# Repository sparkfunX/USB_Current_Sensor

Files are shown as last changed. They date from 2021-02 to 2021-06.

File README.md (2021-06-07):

SparkX USB Current Sensor
========================================

SparkX USB Current Sensor (SPX-18016) (https://www.sparkfun.com/products/18016)

[*SparkX USB Current Sensor (SPX-18016)*](https://www.sparkfun.com/products/18016)

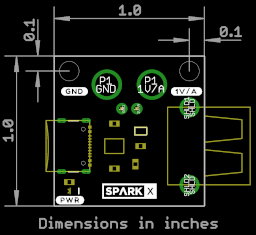
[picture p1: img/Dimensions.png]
SparkX USB Current Sensor


Do you want to be able to measure what current your board is drawing in real time? Maybe it is a board that draws short bursts of current?
Or maybe you want to investigate what in-rush current your board draws? If so, this is the product for you!

The TI INA290 is an ultra-precise current sense amplifier that can measure voltage drops across shunt resistors over a wide common-mode range.
The INA290A1 on our board has a gain of 20 Volts per Volt and we measure the current using a 0.05 Ohm shunt resistor. Together these produce an
output of 1 Volt per Amp. If your board is drawing 100mA, you will see an output of 100mV. The maximum current it can measure is 2 Amps
and we've included a 2A resettable fuse for added protection.

We've provided both 0.1" breakout pads and Gator pads, to make it easy to connect up your multimeter or oscilloscope.
Feed power in via the USB-C socket, and provide power to your board via the USB-A socket.
A pair of [USB 2.0 A to C Cables](https://www.sparkfun.com/products/15092) will allow you to connect the input to your USB port or power supply
and the output to your board.
You might find our [BNC to Alligator Cable](https://www.sparkfun.com/products/504) useful for connecting to your oscilloscope.
Our [Banana to Alligator Coax Cable](https://www.sparkfun.com/products/508) is perfect for connecting your multimeter.

Repository Contents
-------------------
* **/Documents** - datasheets etc.
* **/Hardware** - Eagle design files (.brd, .sch)

Product Versions
----------------
* [SPX-18016](https://www.sparkfun.com/products/18016) - Original SparkX Release.

License Information
-------------------

This product is _**open source**_!

Please review the LICENSE.md file for license information.

If you have any questions or concerns on licensing, please contact technical support on our [SparkFun forums](https://forum.sparkfun.com/viewforum.php?f=152).

Distributed as-is; no warranty is given.

- Your friends at SparkFun.

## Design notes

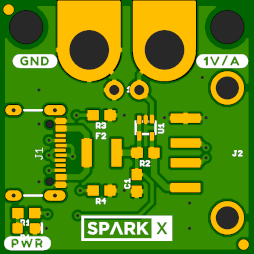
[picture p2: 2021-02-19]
img/Top.png

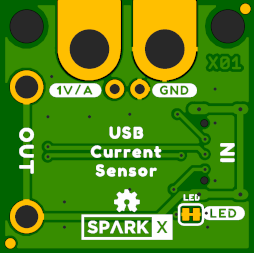
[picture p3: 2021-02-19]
img/Bottom.png

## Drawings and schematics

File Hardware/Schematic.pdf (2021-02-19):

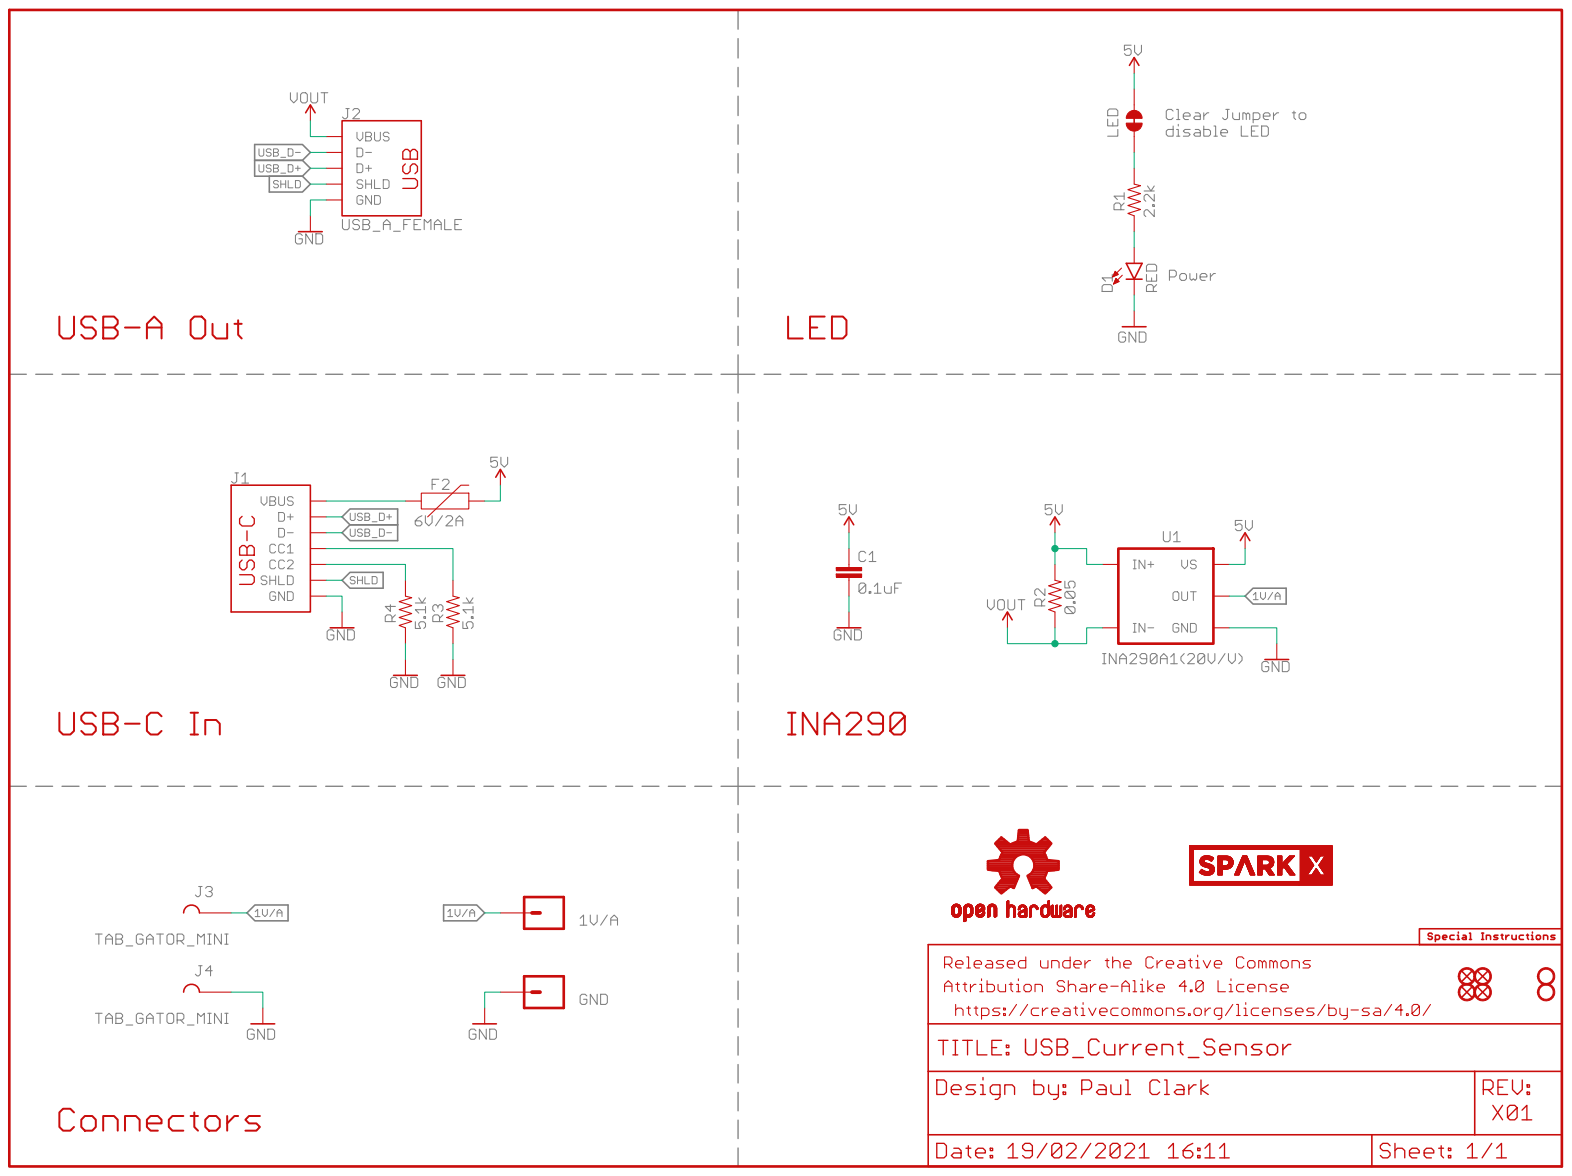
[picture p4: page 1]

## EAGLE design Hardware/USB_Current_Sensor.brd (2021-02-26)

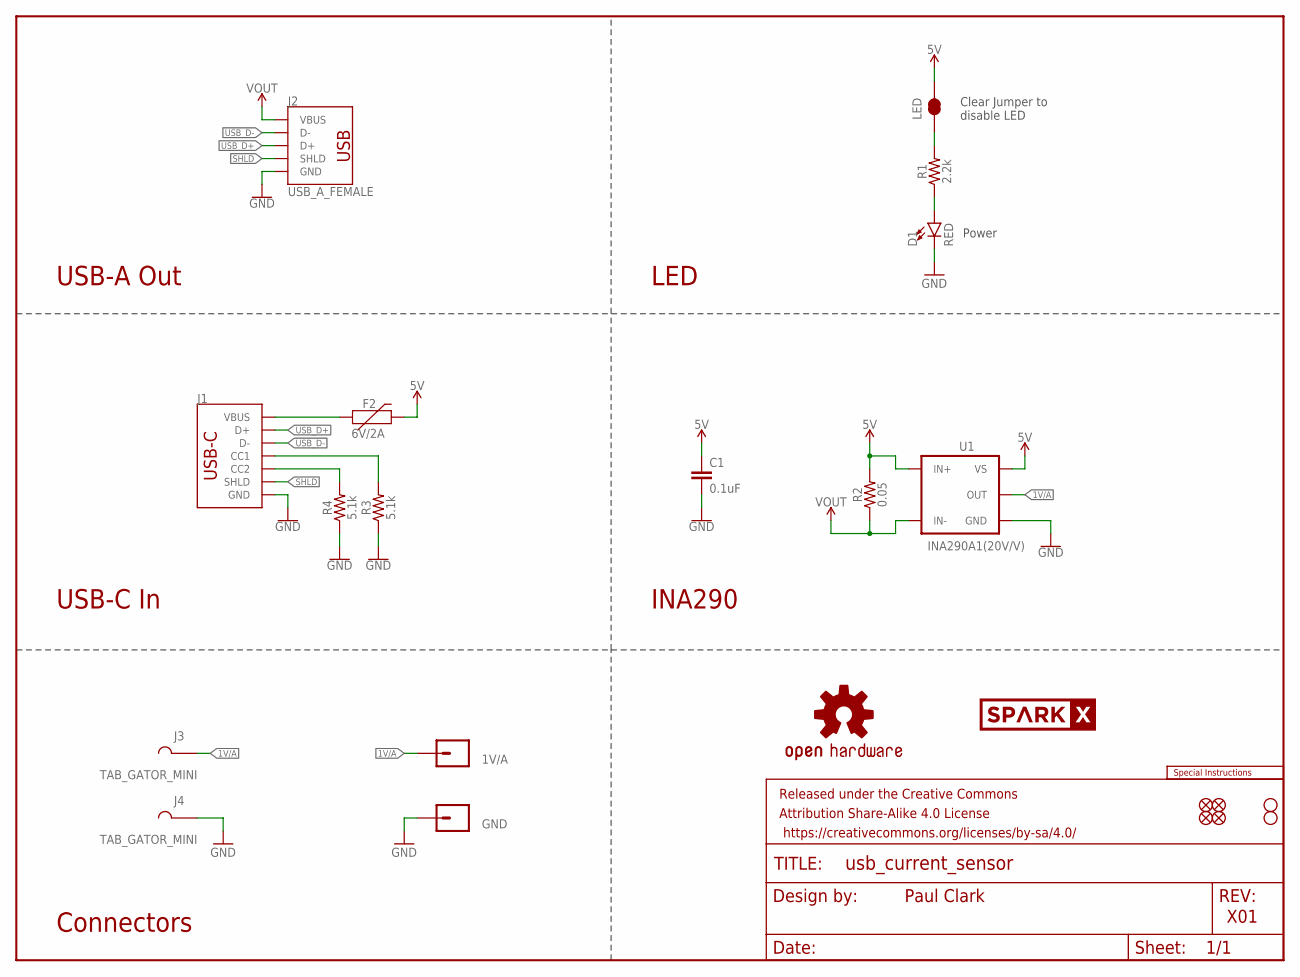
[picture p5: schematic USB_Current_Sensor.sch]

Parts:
1V/A: CONN_01PTH_NO_SILK_YES_STOP; 1X01_NO_SILK
C1: 0.1uF; 0603
D1: RED; LED-0603
F2: 6V/2A; 1210
FRAME1: FRAME-LETTER; CREATIVE_COMMONS
GND: CONN_01PTH_NO_SILK_YES_STOP; 1X01_NO_SILK
J1: USB_C_4-LAYER_PADS; USB-C-16P_4LAYER-PADS
J2: USB_A_FEMALE; USB-A-S-NOSILK-FEMALE
J3, J4: TAB_GATOR_MINI
JP1, JP2, JP5, JP6: FIDUCIAL1X2; FIDUCIAL-1X2
JP3, JP4: STAND-OFF
LED: JUMPER-SMT_2_NC_TRACE_SILK; SMT-JUMPER_2_NC_TRACE_SILK
LOGO1: OSHW-LOGOMINI; OSHW-LOGO-MINI
LOGO2: SPECIAL_INSTRUCTIONS-ORDERING; ORDERING_INSTRUCTIONS
R1: 2.2k; 0603
R2: 0.05; 0603
R3, R4: 5.1k; 0603
U1: INA290A1(20V/V); SC70
U$2: SPARKX-LOGO4; SPARKX-MEDIUM

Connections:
1V/A: 1V/A.1, J3.P1, U1.1 (OUT)
5V: C1.1, F2.2, LED.2, R2.2, U1.3 (VS), U1.4 (IN+)
GND: C1.2, D1.C, GND.1, J1.GND, J1.GND2 (GND), J2.GND, J4.P1, R3.1, R4.1, U1.2 (GND)
unnamed: D1.A, R1.1
unnamed: LED.1, R1.2
unnamed: J1.A5 (CC1), R3.2
unnamed: J1.B5 (CC2), R4.2
unnamed: F2.1, J1.VBUS1 (VBUS), J1.VBUS2 (VBUS)
SHLD: J1.SHLD1 (SHLD), J1.SHLD2 (SHLD), J1.SHLD3 (SHLD), J1.SHLD4 (SHLD), J2.SHLD1 (SHLD), J2.SHLD2 (SHLD)
USB_D+: J1.A6 (D+), J1.B6 (D+), J2.D+
USB_D-: J1.A7 (D-), J1.B7 (D-), J2.D-
VOUT: J2.VBUS, R2.1, U1.5 (IN-)

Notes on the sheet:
Paul Clark
X01
Power
Connectors
Clear Jumper to disable LED
LED
INA290
USB-C In
USB-A Out

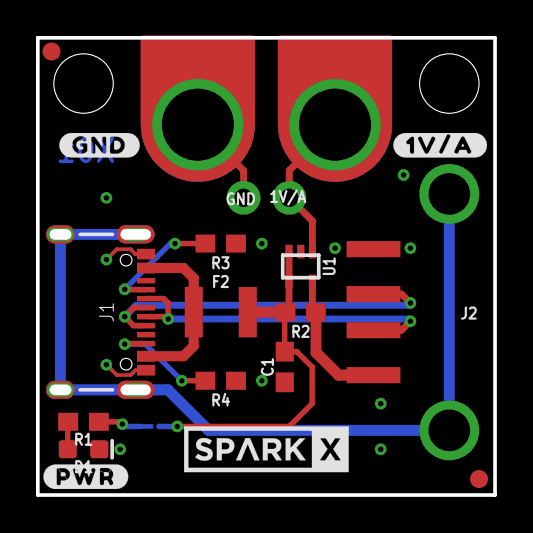
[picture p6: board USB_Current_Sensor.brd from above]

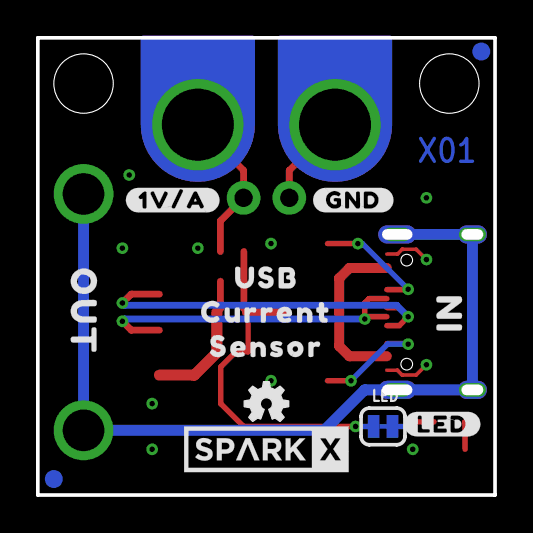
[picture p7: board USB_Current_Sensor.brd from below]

Board: 2 copper layers, 25.4 x 25.4 mm, 37 parts (13 on the bottom side), 12 nets.

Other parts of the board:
U$1: SPARKX-LOGO4; SPARKX-MEDIUM
U$3, U$4: #GND#0
U$5, U$6: #1V#A#0
U$7: USB0
U$8: CURRENT0
U$9: SENSOR0
U$10: IN0
U$11: OUT0
U$13: #PWR#0
U$14: #LED#0

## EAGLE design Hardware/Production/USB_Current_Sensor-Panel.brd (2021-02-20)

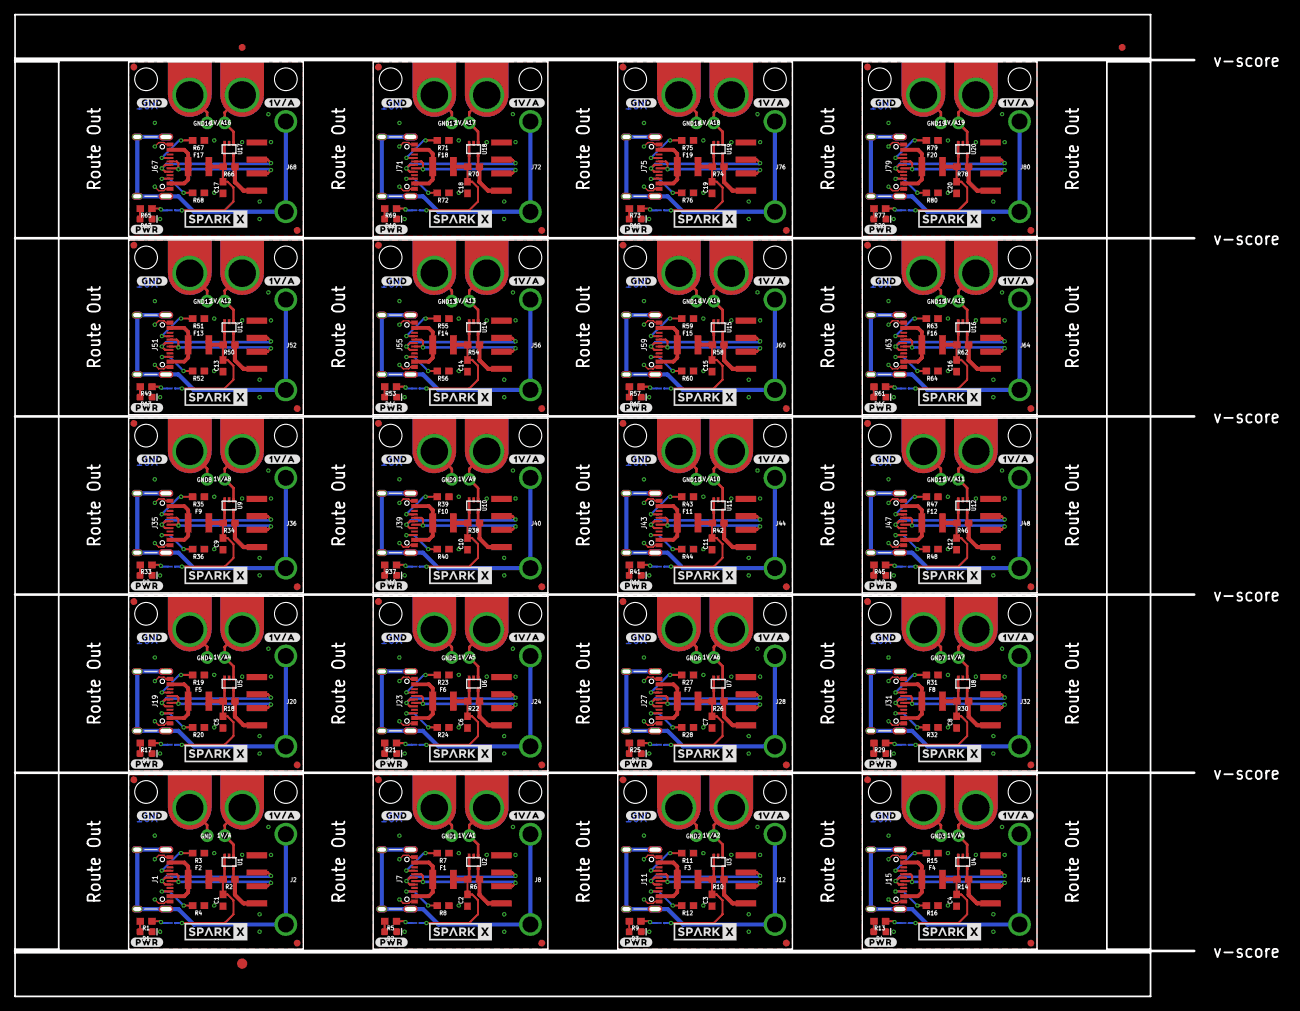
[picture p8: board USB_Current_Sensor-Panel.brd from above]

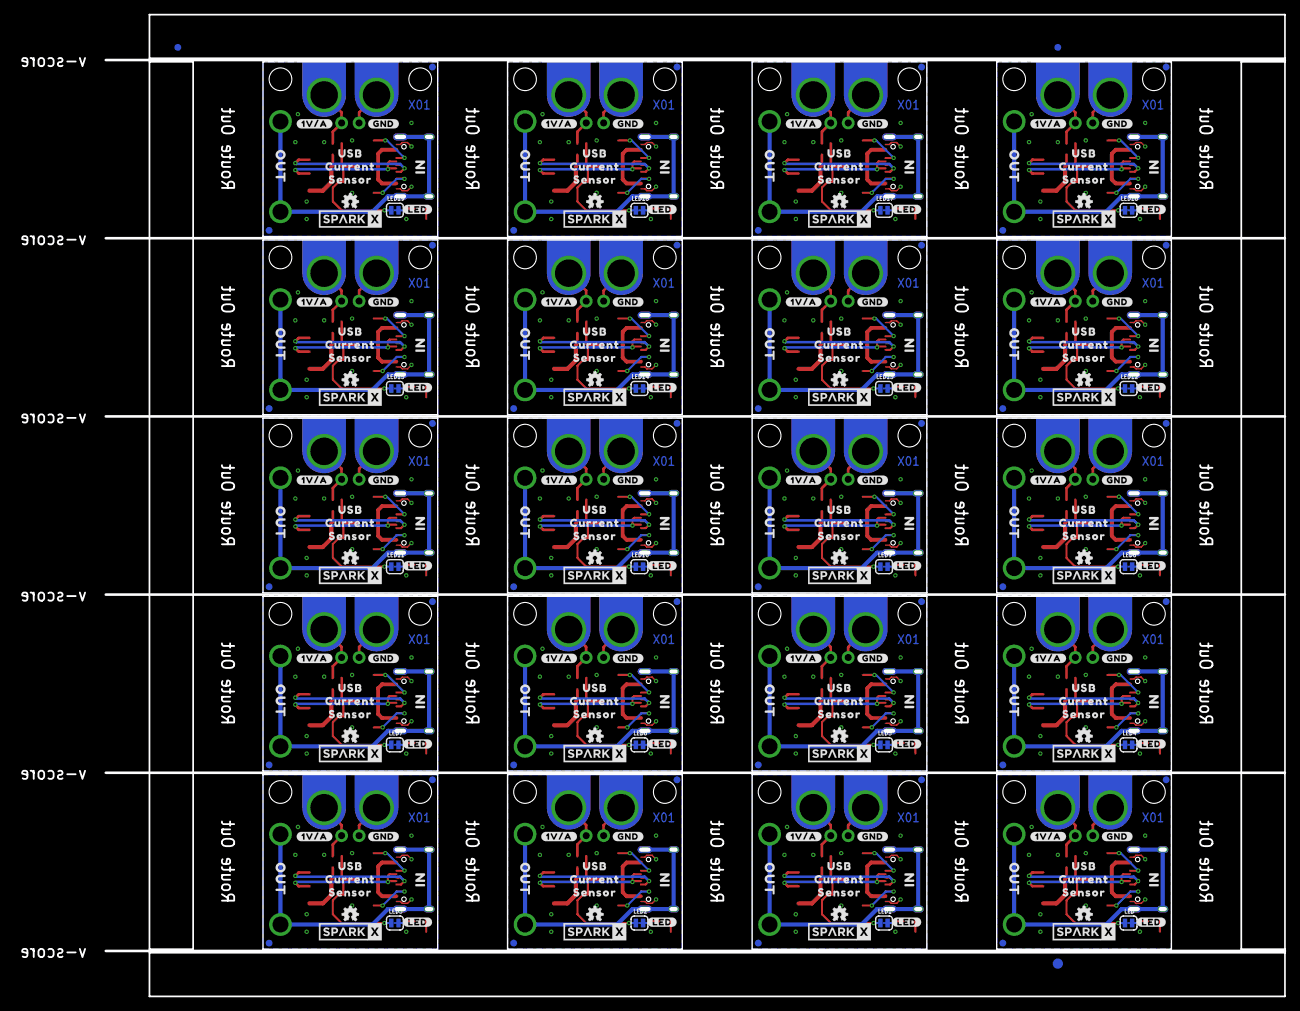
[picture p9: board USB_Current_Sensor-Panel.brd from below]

Board: 2 copper layers, 171.4 x 142.7 mm, 706 parts (263 on the bottom side), 240 nets.

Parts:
1V/A, 1V/A1, 1V/A2, 1V/A3, 1V/A4, 1V/A5, 1V/A6, 1V/A7, 1V/A8, 1V/A9, 1V/A10, 1V/A11, 1V/A12, 1V/A13, 1V/A14, 1V/A15, 1V/A16, 1V/A17, 1V/A18, 1V/A19: 1X01_NO_SILK
C1, C2, C3, C4, C5, C6, C7, C8, C9, C10, C11, C12, C13, C14, C15, C16, C17, C18, C19, C20: 0.1uF; 0603
D1, D2, D3, D4, D5, D6, D7, D8, D9, D10, D11, D12, D13, D14, D15, D16, D17, D18, D19, D20: RED; LED-0603
E$1, E$2, E$3, E$4: FIDUCIAL-1X2
E$5, E$6: FIDUCIAL-1.5X3
F1, F2, F3, F4, F5, F6, F7, F8, F9, F10, F11, F12, F13, F14, F15, F16, F17, F18, F19, F20: 6V/2A; 1210
GND, GND1, GND2, GND3, GND4, GND5, GND6, GND7, GND8, GND9, GND10, GND11, GND12, GND13, GND14, GND15, GND16, GND17, GND18, GND19: 1X01_NO_SILK
J1, J7, J11, J15, J19, J23, J27, J31, J35, J39, J43, J47, J51, J55, J59, J63, J67, J71, J75, J79: USB-C-16P_4LAYER-PADS
J2, J8, J12, J16, J20, J24, J28, J32, J36, J40, J44, J48, J52, J56, J60, J64, J68, J72, J76, J80: USB_A_FEMALE; USB-A-S-NOSILK-FEMALE
J3, J4, J5, J6, J9, J10, J13, J14, J17, J18, J21, J22, J25, J26, J29, J30, J33, J34, J37, J38, J41, J42, J45, J46, J49, J50, J53, J54, J57, J58, J61, J62, J65, J66, J69, J70, J73, J74, J77, J78: TAB_GATOR_MINI
JP1, JP2, JP5, JP6, JP9, JP10, JP11, JP12, JP15, JP16, JP17, JP18, JP21, JP22, JP23, JP24, JP27, JP28, JP29, JP30, JP33, JP34, JP35, JP36, JP39, JP40, JP41, JP42, JP45, JP46, JP47, JP48, JP51, JP52, JP53, JP54, JP57, JP58, JP59, JP60, JP63, JP64, JP65, JP66, JP69, JP70, JP71, JP72, JP75, JP76, JP77, JP78, JP81, JP82, JP83, JP84, JP87, JP88, JP89, JP90, JP93, JP94, JP95, JP96, JP99, JP100, JP101, JP102, JP105, JP106, JP107, JP108, JP111, JP112, JP113, JP114, JP117, JP118, JP119, JP120: FIDUCIAL1X2; FIDUCIAL-1X2
JP3, JP4, JP7, JP8, JP13, JP14, JP19, JP20, JP25, JP26, JP31, JP32, JP37, JP38, JP43, JP44, JP49, JP50, JP55, JP56, JP61, JP62, JP67, JP68, JP73, JP74, JP79, JP80, JP85, JP86, JP91, JP92, JP97, JP98, JP103, JP104, JP109, JP110, JP115, JP116: STAND-OFF
LED, LED1, LED2, LED3, LED4, LED5, LED6, LED7, LED8, LED9, LED10, LED11, LED12, LED13, LED14, LED15, LED16, LED17, LED18, LED19: SMT-JUMPER_2_NC_TRACE_SILK
LOGO1, LOGO2, LOGO3, LOGO4, LOGO5, LOGO6, LOGO7, LOGO8, LOGO9, LOGO10, LOGO11, LOGO12, LOGO13, LOGO14, LOGO15, LOGO16, LOGO17, LOGO18, LOGO19, LOGO20: OSHW-LOGOMINI; OSHW-LOGO-MINI
R1, R5, R9, R13, R17, R21, R25, R29, R33, R37, R41, R45, R49, R53, R57, R61, R65, R69, R73, R77: 2.2k; 0603
R2, R6, R10, R14, R18, R22, R26, R30, R34, R38, R42, R46, R50, R54, R58, R62, R66, R70, R74, R78: 0.05; 0603
R3, R4, R7, R8, R11, R12, R15, R16, R19, R20, R23, R24, R27, R28, R31, R32, R35, R36, R39, R40, R43, R44, R47, R48, R51, R52, R55, R56, R59, R60, R63, R64, R67, R68, R71, R72, R75, R76, R79, R80: 5.1k; 0603
U1, U2, U3, U4, U5, U6, U7, U8, U9, U10, U11, U12, U13, U14, U15, U16, U17, U18, U19, U20: INA290A1(20V/V); SC70
U$1, U$2, U$12, U$17, U$27, U$30, U$40, U$43, U$53, U$56, U$66, U$69, U$79, U$82, U$92, U$95, U$105, U$108, U$118, U$121, U$131, U$134, U$144, U$147, U$157, U$160, U$170, U$173, U$183, U$186, U$196, U$199, U$209, U$212, U$222, U$225, U$235, U$238, U$248, U$251: SPARKX-LOGO4; SPARKX-MEDIUM
U$3, U$4, U$18, U$19, U$31, U$32, U$44, U$45, U$57, U$58, U$70, U$71, U$83, U$84, U$96, U$97, U$109, U$110, U$122, U$123, U$135, U$136, U$148, U$149, U$161, U$162, U$174, U$175, U$187, U$188, U$200, U$201, U$213, U$214, U$226, U$227, U$239, U$240, U$252, U$253: #GND#0
U$5, U$6, U$20, U$21, U$33, U$34, U$46, U$47, U$59, U$60, U$72, U$73, U$85, U$86, U$98, U$99, U$111, U$112, U$124, U$125, U$137, U$138, U$150, U$151, U$163, U$164, U$176, U$177, U$189, U$190, U$202, U$203, U$215, U$216, U$228, U$229, U$241, U$242, U$254, U$255: #1V#A#0
U$7, U$22, U$35, U$48, U$61, U$74, U$87, U$100, U$113, U$126, U$139, U$152, U$165, U$178, U$191, U$204, U$217, U$230, U$243, U$256: USB0
U$8, U$23, U$36, U$49, U$62, U$75, U$88, U$101, U$114, U$127, U$140, U$153, U$166, U$179, U$192, U$205, U$218, U$231, U$244, U$257: CURRENT0
U$9, U$24, U$37, U$50, U$63, U$76, U$89, U$102, U$115, U$128, U$141, U$154, U$167, U$180, U$193, U$206, U$219, U$232, U$245, U$258: SENSOR0
U$10, U$25, U$38, U$51, U$64, U$77, U$90, U$103, U$116, U$129, U$142, U$155, U$168, U$181, U$194, U$207, U$220, U$233, U$246, U$259: IN0
U$11, U$26, U$39, U$52, U$65, U$78, U$91, U$104, U$117, U$130, U$143, U$156, U$169, U$182, U$195, U$208, U$221, U$234, U$247, U$260: OUT0
U$13, U$15, U$28, U$41, U$54, U$67, U$80, U$93, U$106, U$119, U$132, U$145, U$158, U$171, U$184, U$197, U$210, U$223, U$236, U$249: #PWR#0
U$14, U$16, U$29, U$42, U$55, U$68, U$81, U$94, U$107, U$120, U$133, U$146, U$159, U$172, U$185, U$198, U$211, U$224, U$237, U$250: #LED#0

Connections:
1V/A: 1V/A.1, J3.P1, U1.1
1V/A1: 1V/A1.1, J5.P1, U2.1
1V/A2: 1V/A2.1, J9.P1, U3.1
1V/A3: 1V/A3.1, J13.P1, U4.1
1V/A4: 1V/A4.1, J17.P1, U5.1
1V/A5: 1V/A5.1, J21.P1, U6.1
1V/A6: 1V/A6.1, J25.P1, U7.1
1V/A7: 1V/A7.1, J29.P1, U8.1
1V/A8: 1V/A8.1, J33.P1, U9.1
1V/A9: 1V/A9.1, J37.P1, U10.1
1V/A10: 1V/A10.1, J41.P1, U11.1
1V/A11: 1V/A11.1, J45.P1, U12.1
1V/A12: 1V/A12.1, J49.P1, U13.1
1V/A13: 1V/A13.1, J53.P1, U14.1
1V/A14: 1V/A14.1, J57.P1, U15.1
1V/A15: 1V/A15.1, J61.P1, U16.1
1V/A16: 1V/A16.1, J65.P1, U17.1
1V/A17: 1V/A17.1, J69.P1, U18.1
1V/A18: 1V/A18.1, J73.P1, U19.1
1V/A19: 1V/A19.1, J77.P1, U20.1
5V: C1.1, F2.2, LED.2, R2.2, U1.3, U1.4
5V1: C2.1, F1.2, LED1.2, R6.2, U2.3, U2.4
5V2: C3.1, F3.2, LED2.2, R10.2, U3.3, U3.4
5V3: C4.1, F4.2, LED3.2, R14.2, U4.3, U4.4
5V4: C5.1, F5.2, LED4.2, R18.2, U5.3, U5.4
5V5: C6.1, F6.2, LED5.2, R22.2, U6.3, U6.4
5V6: C7.1, F7.2, LED6.2, R26.2, U7.3, U7.4
5V7: C8.1, F8.2, LED7.2, R30.2, U8.3, U8.4
5V8: C9.1, F9.2, LED8.2, R34.2, U9.3, U9.4
5V9: C10.1, F10.2, LED9.2, R38.2, U10.3, U10.4
5V10: C11.1, F11.2, LED10.2, R42.2, U11.3, U11.4
5V11: C12.1, F12.2, LED11.2, R46.2, U12.3, U12.4
5V12: C13.1, F13.2, LED12.2, R50.2, U13.3, U13.4
5V13: C14.1, F14.2, LED13.2, R54.2, U14.3, U14.4
5V14: C15.1, F15.2, LED14.2, R58.2, U15.3, U15.4
5V15: C16.1, F16.2, LED15.2, R62.2, U16.3, U16.4
5V16: C17.1, F17.2, LED16.2, R66.2, U17.3, U17.4
5V17: C18.1, F18.2, LED17.2, R70.2, U18.3, U18.4
5V18: C19.1, F19.2, LED18.2, R74.2, U19.3, U19.4
5V19: C20.1, F20.2, LED19.2, R78.2, U20.3, U20.4
GND: C1.2, D1.C, GND.1, J1.GND, J1.GND2, J2.GND, J4.P1, R3.1, R4.1, U1.2
GND1: C2.2, D2.C, GND1.1, J6.P1, J7.GND, J7.GND2, J8.GND, R7.1, R8.1, U2.2
GND2: C3.2, D3.C, GND2.1, J10.P1, J11.GND, J11.GND2, J12.GND, R11.1, R12.1, U3.2
GND3: C4.2, D4.C, GND3.1, J14.P1, J15.GND, J15.GND2, J16.GND, R15.1, R16.1, U4.2
GND4: C5.2, D5.C, GND4.1, J18.P1, J19.GND, J19.GND2, J20.GND, R19.1, R20.1, U5.2
GND5: C6.2, D6.C, GND5.1, J22.P1, J23.GND, J23.GND2, J24.GND, R23.1, R24.1, U6.2
GND6: C7.2, D7.C, GND6.1, J26.P1, J27.GND, J27.GND2, J28.GND, R27.1, R28.1, U7.2
GND7: C8.2, D8.C, GND7.1, J30.P1, J31.GND, J31.GND2, J32.GND, R31.1, R32.1, U8.2
GND8: C9.2, D9.C, GND8.1, J34.P1, J35.GND, J35.GND2, J36.GND, R35.1, R36.1, U9.2
GND9: C10.2, D10.C, GND9.1, J38.P1, J39.GND, J39.GND2, J40.GND, R39.1, R40.1, U10.2
GND10: C11.2, D11.C, GND10.1, J42.P1, J43.GND, J43.GND2, J44.GND, R43.1, R44.1, U11.2
GND11: C12.2, D12.C, GND11.1, J46.P1, J47.GND, J47.GND2, J48.GND, R47.1, R48.1, U12.2
GND12: C13.2, D13.C, GND12.1, J50.P1, J51.GND, J51.GND2, J52.GND, R51.1, R52.1, U13.2
GND13: C14.2, D14.C, GND13.1, J54.P1, J55.GND, J55.GND2, J56.GND, R55.1, R56.1, U14.2
GND14: C15.2, D15.C, GND14.1, J58.P1, J59.GND, J59.GND2, J60.GND, R59.1, R60.1, U15.2
GND15: C16.2, D16.C, GND15.1, J62.P1, J63.GND, J63.GND2, J64.GND, R63.1, R64.1, U16.2
GND16: C17.2, D17.C, GND16.1, J66.P1, J67.GND, J67.GND2, J68.GND, R67.1, R68.1, U17.2
GND17: C18.2, D18.C, GND17.1, J70.P1, J71.GND, J71.GND2, J72.GND, R71.1, R72.1, U18.2
GND18: C19.2, D19.C, GND18.1, J74.P1, J75.GND, J75.GND2, J76.GND, R75.1, R76.1, U19.2
GND19: C20.2, D20.C, GND19.1, J78.P1, J79.GND, J79.GND2, J80.GND, R79.1, R80.1, U20.2
unnamed: D2.A, R5.1
unnamed: LED1.1, R5.2
unnamed: D1.A, R1.1
unnamed: LED.1, R1.2
unnamed: J7.A5, R7.2
unnamed: J7.B5, R8.2
unnamed: F1.1, J7.VBUS1, J7.VBUS2
unnamed: D3.A, R9.1
unnamed: LED2.1, R9.2
unnamed: J1.A5, R3.2
unnamed: J1.B5, R4.2
unnamed: J11.A5, R11.2
unnamed: J11.B5, R12.2
unnamed: F3.1, J11.VBUS1, J11.VBUS2
unnamed: D4.A, R13.1
unnamed: LED3.1, R13.2
unnamed: J15.A5, R15.2
unnamed: J15.B5, R16.2
unnamed: F2.1, J1.VBUS1, J1.VBUS2
unnamed: F4.1, J15.VBUS1, J15.VBUS2
unnamed: D5.A, R17.1
unnamed: LED4.1, R17.2
unnamed: J19.A5, R19.2
unnamed: J19.B5, R20.2
unnamed: F5.1, J19.VBUS1, J19.VBUS2
unnamed: D6.A, R21.1
unnamed: LED5.1, R21.2
unnamed: J23.A5, R23.2
unnamed: J23.B5, R24.2
unnamed: F6.1, J23.VBUS1, J23.VBUS2
unnamed: D7.A, R25.1
unnamed: LED6.1, R25.2
unnamed: J27.A5, R27.2
unnamed: J27.B5, R28.2
unnamed: F7.1, J27.VBUS1, J27.VBUS2
unnamed: D8.A, R29.1
unnamed: LED7.1, R29.2
unnamed: J31.A5, R31.2
unnamed: J31.B5, R32.2
unnamed: F8.1, J31.VBUS1, J31.VBUS2
unnamed: D9.A, R33.1
unnamed: LED8.1, R33.2
unnamed: J35.A5, R35.2
unnamed: J35.B5, R36.2
unnamed: F9.1, J35.VBUS1, J35.VBUS2
unnamed: D10.A, R37.1
unnamed: LED9.1, R37.2
unnamed: J39.A5, R39.2
unnamed: J39.B5, R40.2
unnamed: F10.1, J39.VBUS1, J39.VBUS2
unnamed: D11.A, R41.1
unnamed: LED10.1, R41.2
unnamed: J43.A5, R43.2
unnamed: J43.B5, R44.2
unnamed: F11.1, J43.VBUS1, J43.VBUS2
unnamed: D12.A, R45.1
unnamed: LED11.1, R45.2
unnamed: J47.A5, R47.2
unnamed: J47.B5, R48.2
unnamed: F12.1, J47.VBUS1, J47.VBUS2
unnamed: D13.A, R49.1
unnamed: LED12.1, R49.2
unnamed: J51.A5, R51.2
unnamed: J51.B5, R52.2
unnamed: F13.1, J51.VBUS1, J51.VBUS2
unnamed: D14.A, R53.1
unnamed: LED13.1, R53.2
unnamed: J55.A5, R55.2
unnamed: J55.B5, R56.2
unnamed: F14.1, J55.VBUS1, J55.VBUS2
unnamed: D15.A, R57.1
unnamed: LED14.1, R57.2
unnamed: J59.A5, R59.2
unnamed: J59.B5, R60.2
unnamed: F15.1, J59.VBUS1, J59.VBUS2
unnamed: D16.A, R61.1
unnamed: LED15.1, R61.2
unnamed: J63.A5, R63.2
unnamed: J63.B5, R64.2
unnamed: F16.1, J63.VBUS1, J63.VBUS2
unnamed: D17.A, R65.1
unnamed: LED16.1, R65.2
unnamed: J67.A5, R67.2
unnamed: J67.B5, R68.2
unnamed: F17.1, J67.VBUS1, J67.VBUS2
unnamed: D18.A, R69.1
unnamed: LED17.1, R69.2
unnamed: J71.A5, R71.2
unnamed: J71.B5, R72.2
unnamed: F18.1, J71.VBUS1, J71.VBUS2
unnamed: D19.A, R73.1
unnamed: LED18.1, R73.2
unnamed: J75.A5, R75.2
unnamed: J75.B5, R76.2
unnamed: F19.1, J75.VBUS1, J75.VBUS2
unnamed: D20.A, R77.1
unnamed: LED19.1, R77.2
unnamed: J79.A5, R79.2
unnamed: J79.B5, R80.2
unnamed: F20.1, J79.VBUS1, J79.VBUS2
SHLD: J1.SHLD1, J1.SHLD2, J1.SHLD3, J1.SHLD4, J2.SHLD1, J2.SHLD2
SHLD1: J7.SHLD1, J7.SHLD2, J7.SHLD3, J7.SHLD4, J8.SHLD1, J8.SHLD2
SHLD2: J11.SHLD1, J11.SHLD2, J11.SHLD3, J11.SHLD4, J12.SHLD1, J12.SHLD2
SHLD3: J15.SHLD1, J15.SHLD2, J15.SHLD3, J15.SHLD4, J16.SHLD1, J16.SHLD2
SHLD4: J19.SHLD1, J19.SHLD2, J19.SHLD3, J19.SHLD4, J20.SHLD1, J20.SHLD2
SHLD5: J23.SHLD1, J23.SHLD2, J23.SHLD3, J23.SHLD4, J24.SHLD1, J24.SHLD2
SHLD6: J27.SHLD1, J27.SHLD2, J27.SHLD3, J27.SHLD4, J28.SHLD1, J28.SHLD2
SHLD7: J31.SHLD1, J31.SHLD2, J31.SHLD3, J31.SHLD4, J32.SHLD1, J32.SHLD2
SHLD8: J35.SHLD1, J35.SHLD2, J35.SHLD3, J35.SHLD4, J36.SHLD1, J36.SHLD2
SHLD9: J39.SHLD1, J39.SHLD2, J39.SHLD3, J39.SHLD4, J40.SHLD1, J40.SHLD2
SHLD10: J43.SHLD1, J43.SHLD2, J43.SHLD3, J43.SHLD4, J44.SHLD1, J44.SHLD2
SHLD11: J47.SHLD1, J47.SHLD2, J47.SHLD3, J47.SHLD4, J48.SHLD1, J48.SHLD2
SHLD12: J51.SHLD1, J51.SHLD2, J51.SHLD3, J51.SHLD4, J52.SHLD1, J52.SHLD2
SHLD13: J55.SHLD1, J55.SHLD2, J55.SHLD3, J55.SHLD4, J56.SHLD1, J56.SHLD2
SHLD14: J59.SHLD1, J59.SHLD2, J59.SHLD3, J59.SHLD4, J60.SHLD1, J60.SHLD2
SHLD15: J63.SHLD1, J63.SHLD2, J63.SHLD3, J63.SHLD4, J64.SHLD1, J64.SHLD2
SHLD16: J67.SHLD1, J67.SHLD2, J67.SHLD3, J67.SHLD4, J68.SHLD1, J68.SHLD2
SHLD17: J71.SHLD1, J71.SHLD2, J71.SHLD3, J71.SHLD4, J72.SHLD1, J72.SHLD2
SHLD18: J75.SHLD1, J75.SHLD2, J75.SHLD3, J75.SHLD4, J76.SHLD1, J76.SHLD2
SHLD19: J79.SHLD1, J79.SHLD2, J79.SHLD3, J79.SHLD4, J80.SHLD1, J80.SHLD2
USB_D+: J1.A6, J1.B6, J2.D+
USB_D+1: J7.A6, J7.B6, J8.D+
USB_D+2: J11.A6, J11.B6, J12.D+
USB_D+3: J15.A6, J15.B6, J16.D+
USB_D+4: J19.A6, J19.B6, J20.D+
USB_D+5: J23.A6, J23.B6, J24.D+
USB_D+6: J27.A6, J27.B6, J28.D+
USB_D+7: J31.A6, J31.B6, J32.D+
USB_D+8: J35.A6, J35.B6, J36.D+
USB_D+9: J39.A6, J39.B6, J40.D+
USB_D+10: J43.A6, J43.B6, J44.D+
USB_D+11: J47.A6, J47.B6, J48.D+
USB_D+12: J51.A6, J51.B6, J52.D+
USB_D+13: J55.A6, J55.B6, J56.D+
USB_D+14: J59.A6, J59.B6, J60.D+
USB_D+15: J63.A6, J63.B6, J64.D+
USB_D+16: J67.A6, J67.B6, J68.D+
USB_D+17: J71.A6, J71.B6, J72.D+
USB_D+18: J75.A6, J75.B6, J76.D+
USB_D+19: J79.A6, J79.B6, J80.D+
USB_D-: J1.A7, J1.B7, J2.D-
USB_D-1: J7.A7, J7.B7, J8.D-
USB_D-2: J11.A7, J11.B7, J12.D-
USB_D-3: J15.A7, J15.B7, J16.D-
USB_D-4: J19.A7, J19.B7, J20.D-
USB_D-5: J23.A7, J23.B7, J24.D-
USB_D-6: J27.A7, J27.B7, J28.D-
USB_D-7: J31.A7, J31.B7, J32.D-
USB_D-8: J35.A7, J35.B7, J36.D-
USB_D-9: J39.A7, J39.B7, J40.D-
USB_D-10: J43.A7, J43.B7, J44.D-
USB_D-11: J47.A7, J47.B7, J48.D-
USB_D-12: J51.A7, J51.B7, J52.D-
USB_D-13: J55.A7, J55.B7, J56.D-
USB_D-14: J59.A7, J59.B7, J60.D-
USB_D-15: J63.A7, J63.B7, J64.D-
USB_D-16: J67.A7, J67.B7, J68.D-
USB_D-17: J71.A7, J71.B7, J72.D-
USB_D-18: J75.A7, J75.B7, J76.D-
USB_D-19: J79.A7, J79.B7, J80.D-
VOUT: J2.VBUS, R2.1, U1.5
VOUT1: J8.VBUS, R6.1, U2.5
VOUT2: J12.VBUS, R10.1, U3.5
VOUT3: J16.VBUS, R14.1, U4.5
VOUT4: J20.VBUS, R18.1, U5.5
VOUT5: J24.VBUS, R22.1, U6.5
VOUT6: J28.VBUS, R26.1, U7.5
VOUT7: J32.VBUS, R30.1, U8.5
VOUT8: J36.VBUS, R34.1, U9.5
VOUT9: J40.VBUS, R38.1, U10.5
VOUT10: J44.VBUS, R42.1, U11.5
VOUT11: J48.VBUS, R46.1, U12.5
VOUT12: J52.VBUS, R50.1, U13.5
VOUT13: J56.VBUS, R54.1, U14.5
VOUT14: J60.VBUS, R58.1, U15.5
VOUT15: J64.VBUS, R62.1, U16.5
VOUT16: J68.VBUS, R66.1, U17.5
VOUT17: J72.VBUS, R70.1, U18.5
VOUT18: J76.VBUS, R74.1, U19.5
VOUT19: J80.VBUS, R78.1, U20.5

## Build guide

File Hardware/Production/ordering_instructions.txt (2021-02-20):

panel size, 166x143mm
PCB thickness, 1.6mm
number of layers, 2
soldermask color, Black
silkscreen color, White
oz copper, 1oz
finish, HASL lead free
stencils, top
pcs per panel, 20
min trace width, 0.2032mm / 0.0080in
min drill size, 0.3000mm / 0.0118in

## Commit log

2021-02-20 Adding production files
    [USB_Current_Sensor-Panel.GBL, USB_Current_Sensor-Panel.GBO, USB_Current_Sensor-Panel.GBP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]
2021-02-26 Correcting the PROD_ID
    [USB_Current_Sensor.brd, USB_Current_Sensor.sch]

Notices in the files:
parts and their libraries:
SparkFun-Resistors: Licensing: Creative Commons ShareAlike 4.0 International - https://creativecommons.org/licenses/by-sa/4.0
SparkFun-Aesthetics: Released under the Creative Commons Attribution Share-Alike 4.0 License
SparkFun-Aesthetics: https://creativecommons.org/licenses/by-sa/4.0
